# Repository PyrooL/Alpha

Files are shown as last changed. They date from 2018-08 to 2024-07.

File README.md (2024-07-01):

# Alpha 

A 28-key semi-ortholinear mechanical keyboard designed by PyroL.

example

###### Photo by /u/Polyzhu.

## History

[First ever post](https://www.reddit.com/r/MechanicalKeyboards/comments/7nz4ge/ic_i_was_challenged_to_reduce_the_gherkin_and/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)

[PCB protos arrive](https://www.reddit.com/r/MechanicalKeyboards/comments/887hxn/its_so_cute_c/?ref=share&ref_source=link)

[GB opens](https://www.reddit.com/r/MechanicalKeyboards/comments/8djw3d/gb_alpha_28key_keyboard/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)

# Build instructions

## Parts

- [ ] 1x Alpha PCB
- [ ] 28x 1N4148 or equivalent diodes
- [ ] 1x Pro Micro (**NOTE:** USB-C ports are experiencing some clearance issues since it's taller than Micro-B)
- [ ] 1x Case or plate set
- [ ] 5x 10mm M3 standoffs
- [ ] 10x 5mm M3 screws
- [ ] 28x MX, Alps, or Kailh Choc style switches of your choice
- [ ] 1x Micro USB cable

## Tools

- [ ] Soldering station
- [ ] Wire cutter
- [ ] Screwdriver

## Before you start

Orient the PCB correctly before you start the build: the blockers on the side closer to you, and the Pro Micro holes on the left. You should be able to read the "Too. Many. Keys." slogan on the side facing up.

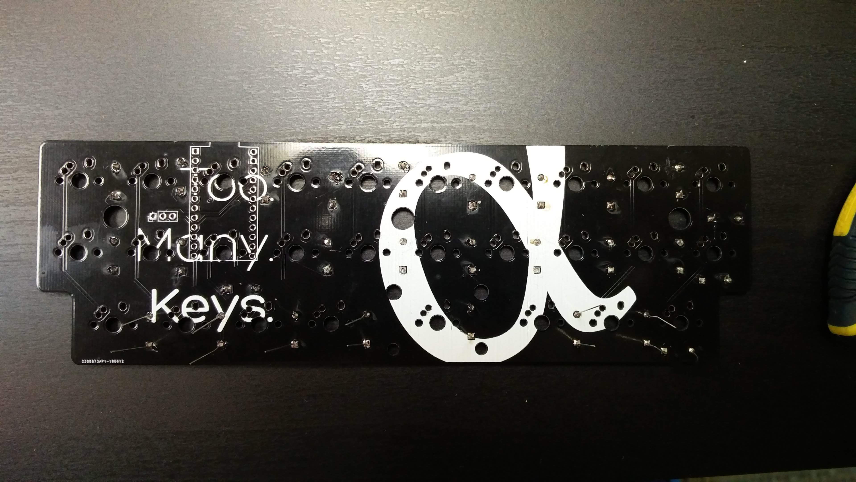
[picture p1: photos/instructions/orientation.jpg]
orientation
 

(OPTIONAL): Install a 2u stabilizer.

## Step 1: Diodes

Install and solder the diodes on the bottom of the PCB, with the black line facing the square pad. Cut the excess leads. 

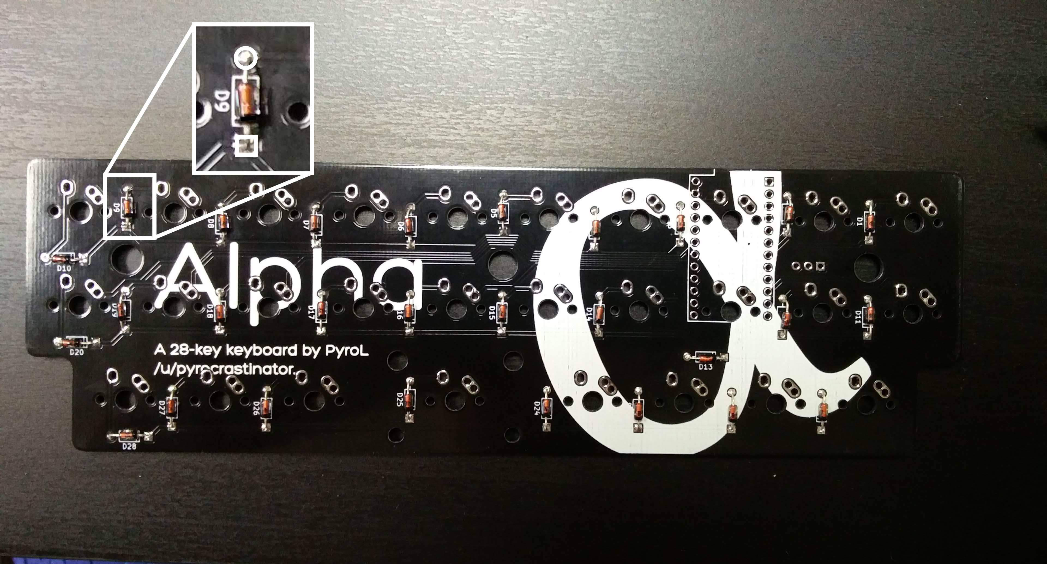
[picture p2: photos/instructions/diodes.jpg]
diodes


## Step 2: Pro Micro
Insert the short side of the Pro Micro standoffs into the bottom of the PCB, and solder them in from the top.

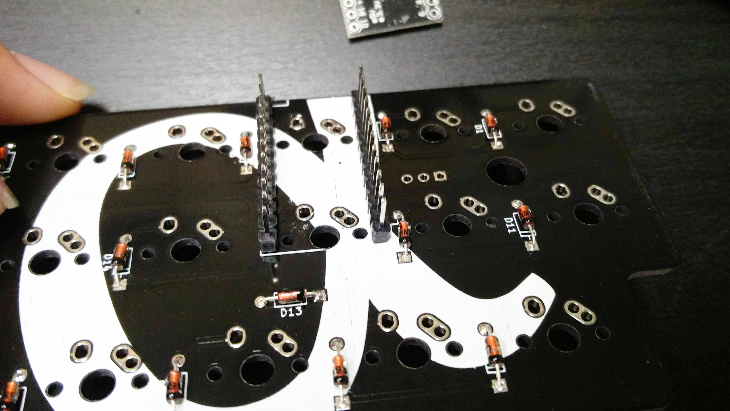
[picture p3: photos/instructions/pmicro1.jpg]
pmicro standoff bottom


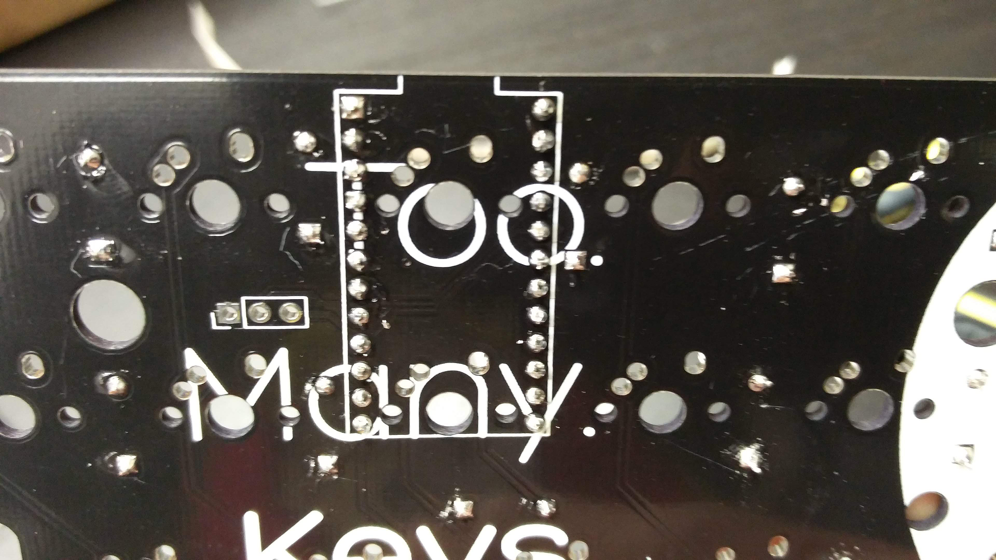
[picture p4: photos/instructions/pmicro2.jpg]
pmicro standoff soldered


Mount the two switches that will sit in between the Pro Micro standoffs in the plate and solder them into the PCB at that location. Clip the extruding switch pins after soldering to ensure the Pro Micro will sit flat. 

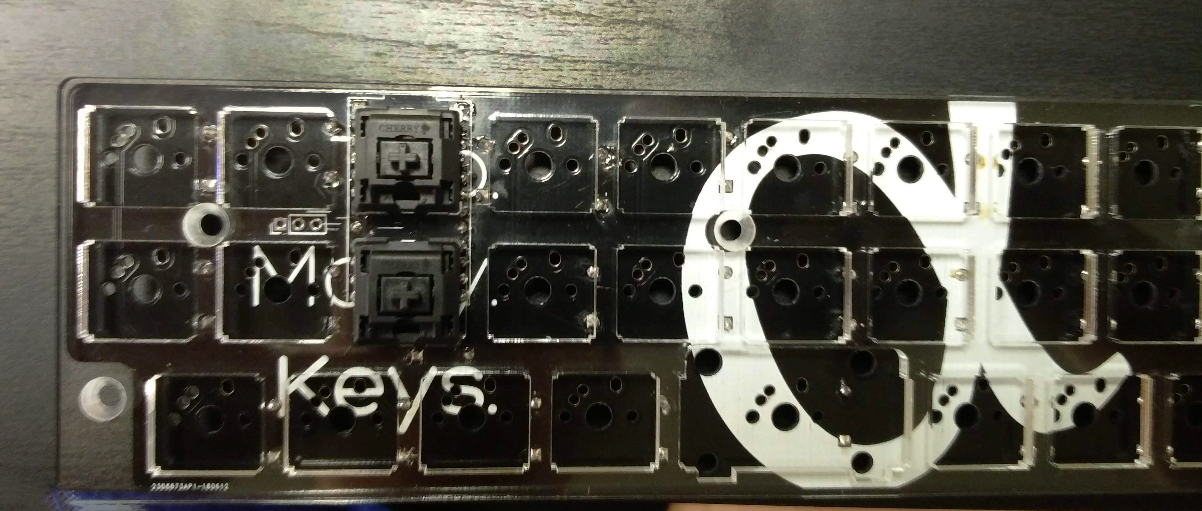
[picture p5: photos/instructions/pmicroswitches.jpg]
pmicro switches


Mount the Pro Micro on the bottom of the PCB, smooth side facing you. Solder.

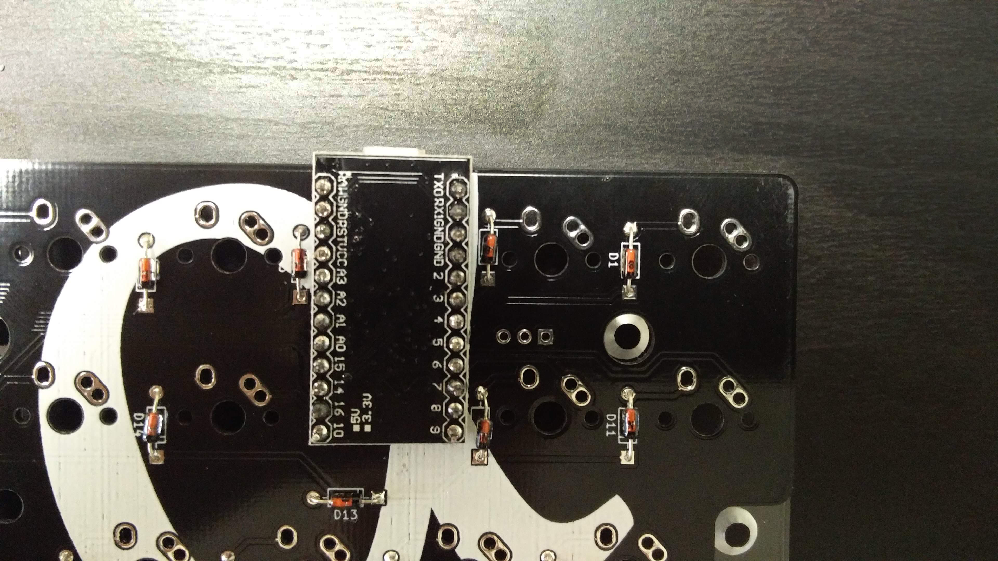
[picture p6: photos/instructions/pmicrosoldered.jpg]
pmicro


[bakingpy has an awesome guide](https://imgur.com/a/M9r3EW9) for an even lower-profile Pro Micro mounting solution that works with Alpha!

**Very important:** after soldering, (regardless of if you mounted normally or bakingpy-style,) use a wire cutter to clip as much of the protruding standoff as possible. With 10mm standoffs this is a snug fit, and it is impossible with the standoffs at full length. Reflow your solder if it climbed up the wire.

## Step 3: Switches

Mount the switches in the plate, and solder them all in. Careful for bent pins!

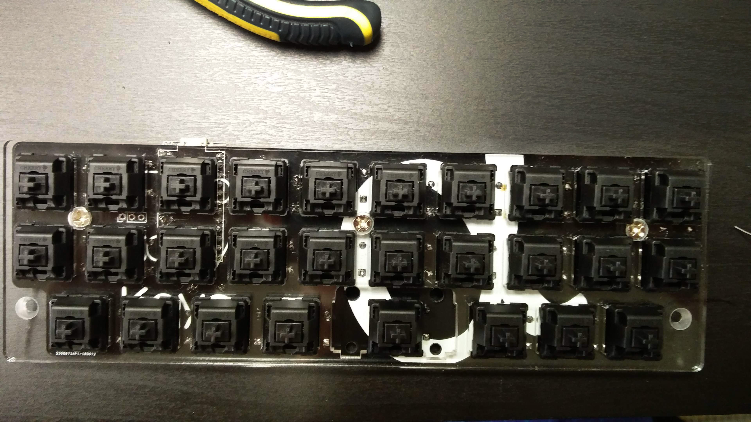
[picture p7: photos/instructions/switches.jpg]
switches


## Step 4 (OPTIONAL): LED strip

Remove the 3M adhesive strip on the back of your LED strip and place it on the bottom of the PCB. Cut 3 wires of similar length, preferably of different colors. Connect VCC, GND, and Data pins on the strip to their respective pins on the PCB.

v1.1 and onwards has pins labeled and in the same order as they come on the strip!

[**If you are using a v1.0 PCB (one that does not have RGB pins or version number labeled) see here for wiring guide**](photos/instructions/rgb.jpg)

## Step 5: Case and firmware

Assemble the case: for each hole, pass a screw through the top plate, screw in a standoff to finger tightness, then screw in through the bottom plate. Once all screws and standoffs are installed, use a screwdriver to tighten as needed (but not too tight, as acrylic can be brittle!). Flash using QMK (use my firmware, or kbfirmware.com), and enjoy!

Flash steps:

- Download [QMK Toolbox](https://github.com/qmk/qmk_toolbox)
- Ensure that you have an appropriate firmware file.
  - For Vial, you can download one off of [keyboard.gay](https://keyboard.gay)
- Open QMK Toolbox. Plug your PCB in, and press the SKQG reset button (or short the appropriate headers). You should see the device connect for ~10 seconds, then disconnect.
- Within QMK Toolbox, choose your appropriate firmware file, then check the "Auto-Flash" button.
- Reset your board again. The firmware should be automatically flashed onto the board.

Don't forget to send me a pic of your build at @PyroL#7672 on Discord or /u/pyrocrastinator! I'd love to see what you guys do with these! 

# Changelog
* v1.1 3/2/19

Added SKQG reset button pads (no need to manually short reset!) and fixed RGB pin order to match common SK6812/WS2812 pinout, and added silkscreen labels to RGB pins.

* v1.2 4/27/19

Diodes now are combo through-hole and SMD compatible! Breakout pins for artisan column ("tmo28") added on both sides. Routing cleaned up etc. 

* v2.0 7/21/19

Choc footprints added! Also support for first version of "TMO28", an artisan column that's still being worked on. 

* v2.1 9/1/19

Fixed disconnected D4, see [here](https://www.instagram.com/p/B15MHgMnYID/?igshid=1266ym89zlw4w) or contact me for fix if you are affected. Only affects v2.0.

* v2.2 7/24/20

Removed TMO28 breakout pins for cleaner look. Version with breakouts still available in `breakoutholes` branch.

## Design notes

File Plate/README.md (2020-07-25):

# Instructions

SVG and Illustrator file for top and bottom plate. If importing into a CAD program, convert it to DXF first or verify the dimensions are correct when you import it. 

Countersinking mounting holes may be done manually with a drill press.

3mm acrylic needs a cutout for stab wire.

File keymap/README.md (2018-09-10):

# A guide to the keymap

In this document I will go through the basic functionality of the Alpha's default keymap. Several functions are kept consistent throughout all the layers. 

 - last key on the 2nd row toggles the next layer. This is not a hold function, just one tap switches.

 - The key to the left of the spacebar returns to the home layer.

The default keymap is somewhat organized by function:

 - Home layer: All letters, spacebar is shift on hold.

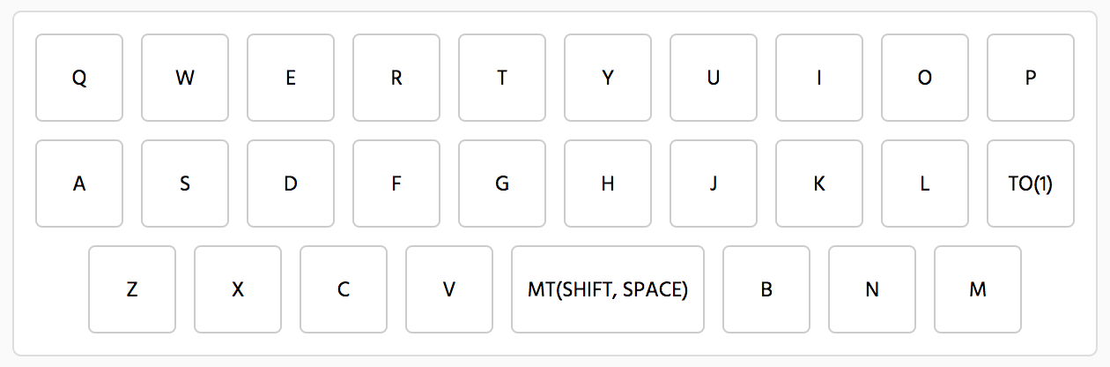
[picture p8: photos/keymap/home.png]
home layer
 

 - Mod layer 1: numbers on top row, vim keys, essential punctuation, and essential mods (Ctrl, OS, Alt, Backspace, Tab, Esc). Enter is on spacebar tap, but shift works the same way. 
 
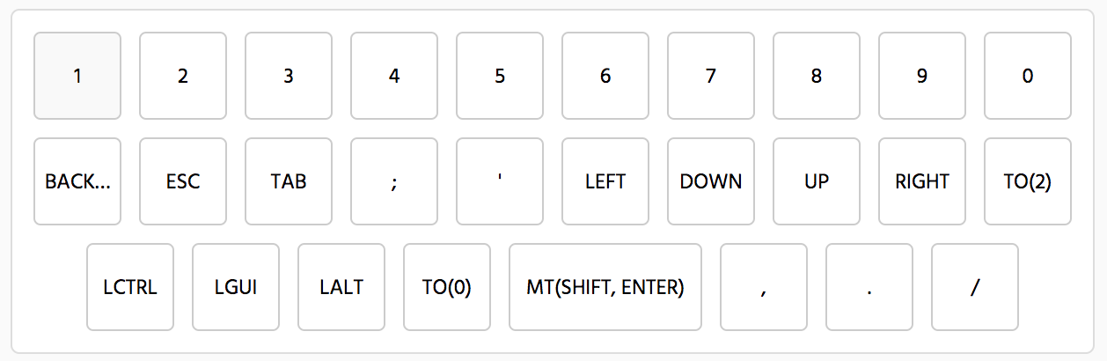
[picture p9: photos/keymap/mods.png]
mods
 

 - Mod layer 2: function keys, RGB control, basic media controls, and math. 
 
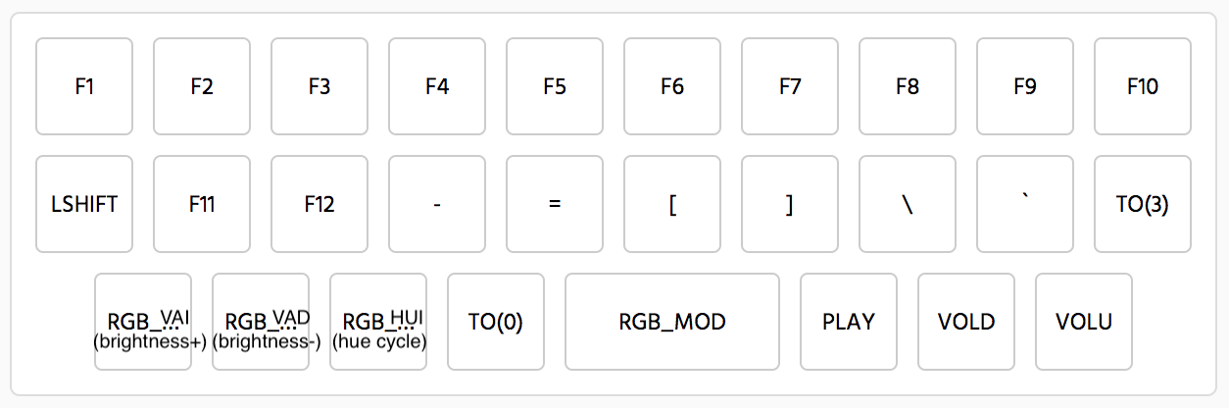
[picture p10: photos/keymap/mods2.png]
mods 2


The final layer has a soft reset button on Q, and spacebar is macro with a special little message from me :)

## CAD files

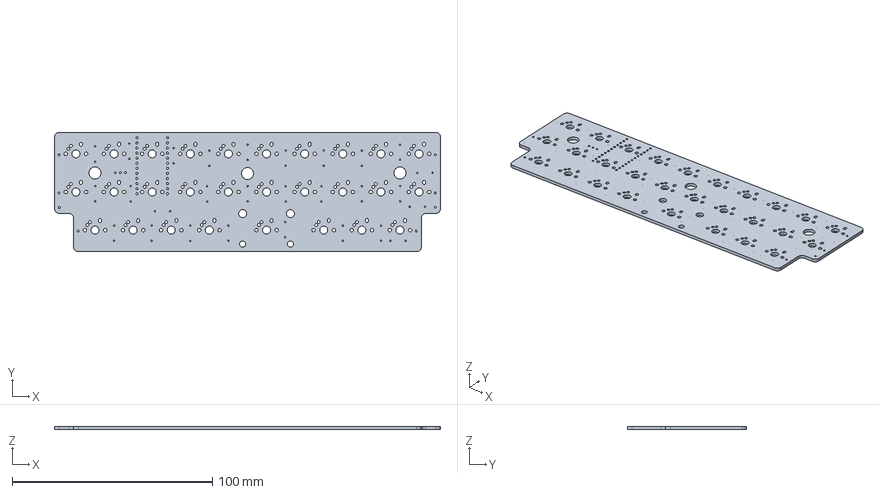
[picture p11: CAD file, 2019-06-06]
PCB_kicad/alpha_pro_micro.step
192.9 x 59.5 x 1.60 mm

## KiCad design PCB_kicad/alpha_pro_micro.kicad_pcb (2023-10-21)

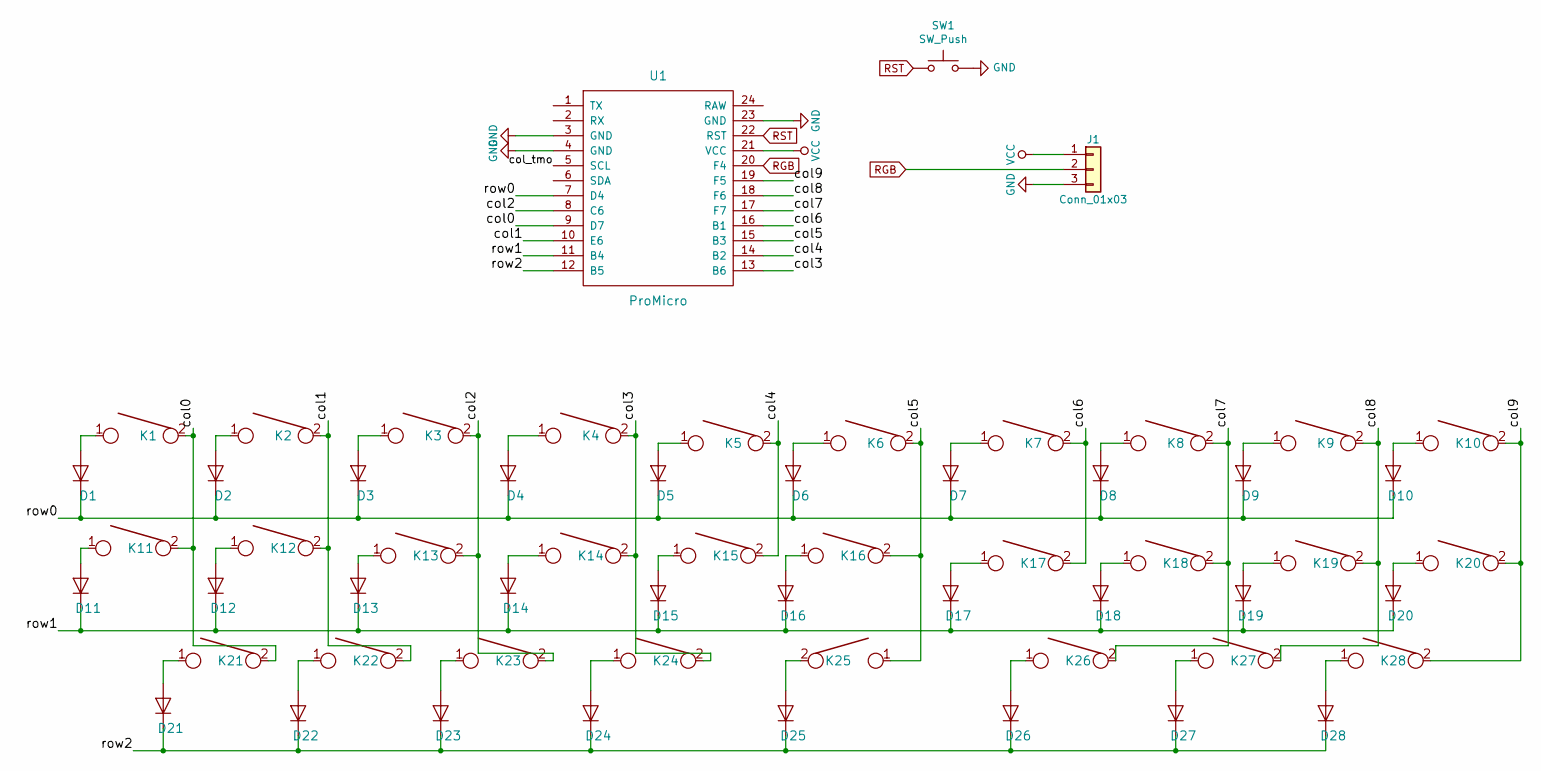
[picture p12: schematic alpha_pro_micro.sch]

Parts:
D1, D2, D3, D4, D5, D6, D7, D8, D9, D10, D11, D12, D13, D14, D15, D16, D17, D18, D19, D20, D21, D22, D23, D24, D25, D26, D27, D28: D; ComboDiode
J1: Conn_01x03; Pin_Header_Straight_1x03_Pitch2.54mm
K1, K2, K3, K4, K5, K6, K7, K8, K9, K10, K11, K12, K13, K14, K15, K16, K17, K18, K19, K20, K21, K22, K23, K24, K26, K27, K28: KEYSW; MX-Alps-Choc-1U-NoLED
K25: KEYSW; MX-Alps-Choc-2U-StabFlip
SW1: SW_Push; SKQG-1155865
U1: ProMicro

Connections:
/col0: K1.2, K11.2, K21.2, U1.9 (D7)
/col1: K2.2, K12.2, K22.2, U1.10 (E6)
/col2: K3.2, K13.2, K23.2, U1.8 (C6)
/col3: K4.2, K14.2, K24.2, U1.13 (B6)
/col4: K5.2, K15.2, U1.14 (B2)
/col5: K6.2, K16.2, K25.1, U1.15 (B3)
/col6: K7.2, K17.2, U1.16 (B1)
/col7: K8.2, K18.2, K26.2, U1.17 (F7)
/col8: K9.2, K19.2, K27.2, U1.18 (F6)
/col9: K10.2, K20.2, K28.2, U1.19 (F5)
/col_tmo: U1.5 (SCL)
/row0: D1.1 (K), D2.1 (K), D3.1 (K), D4.1 (K), D5.1 (K), D6.1 (K), D7.1 (K), D8.1 (K), D9.1 (K), D10.1 (K), U1.7 (D4)
/row1: D11.1 (K), D12.1 (K), D13.1 (K), D14.1 (K), D15.1 (K), D16.1 (K), D17.1 (K), D18.1 (K), D19.1 (K), D20.1 (K), U1.11 (B4)
/row2: D21.1 (K), D22.1 (K), D23.1 (K), D24.1 (K), D25.1 (K), D26.1 (K), D27.1 (K), D28.1 (K), U1.12 (B5)
GND: J1.3, SW1.2, U1.3 (GND), U1.4 (GND), U1.23 (GND)
unnamed: D1.2 (A), K1.1
unnamed: D2.2 (A), K2.1
unnamed: D3.2 (A), K3.1
unnamed: D4.2 (A), K4.1
unnamed: D5.2 (A), K5.1
unnamed: D6.2 (A), K6.1
unnamed: D7.2 (A), K7.1
unnamed: D8.2 (A), K8.1
unnamed: D9.2 (A), K9.1
unnamed: D10.2 (A), K10.1
unnamed: D11.2 (A), K11.1
unnamed: D12.2 (A), K12.1
unnamed: D13.2 (A), K13.1
unnamed: D14.2 (A), K14.1
unnamed: D15.2 (A), K15.1
unnamed: D16.2 (A), K16.1
unnamed: D17.2 (A), K17.1
unnamed: D18.2 (A), K18.1
unnamed: D19.2 (A), K19.1
unnamed: D20.2 (A), K20.1
unnamed: D21.2 (A), K21.1
unnamed: D22.2 (A), K22.1
unnamed: D23.2 (A), K23.1
unnamed: D24.2 (A), K24.1
unnamed: D25.2 (A), K25.2
unnamed: D26.2 (A), K26.1
unnamed: D27.2 (A), K27.1
unnamed: D28.2 (A), K28.1
RGB: J1.2, U1.20 (F4)
RST: SW1.1, U1.22 (RST)
VCC: J1.1, U1.21 (VCC)

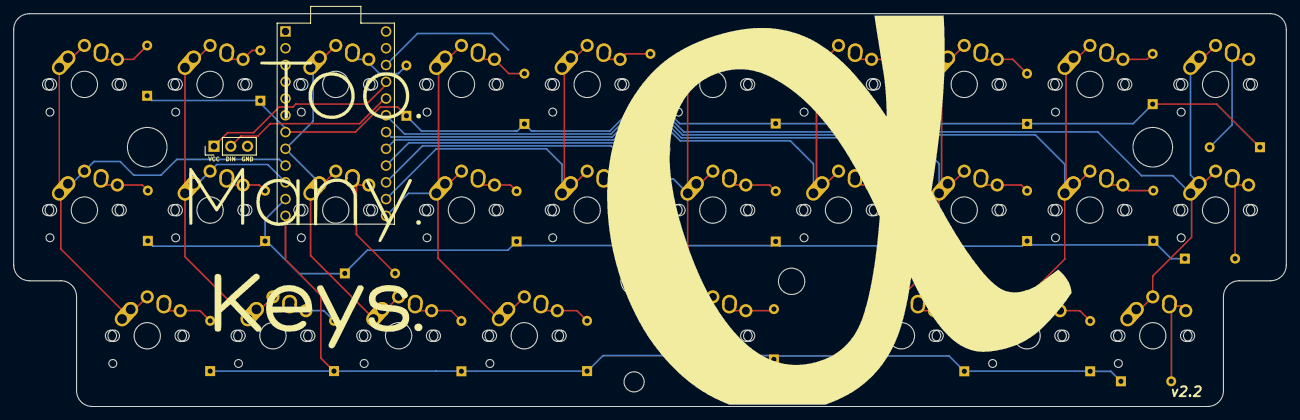
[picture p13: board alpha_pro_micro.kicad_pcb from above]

Board: 2 copper layers, 192.9 x 59.5 mm, 60 parts (1 on the bottom side), 45 nets.

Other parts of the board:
HC1: MountingHole_6mm

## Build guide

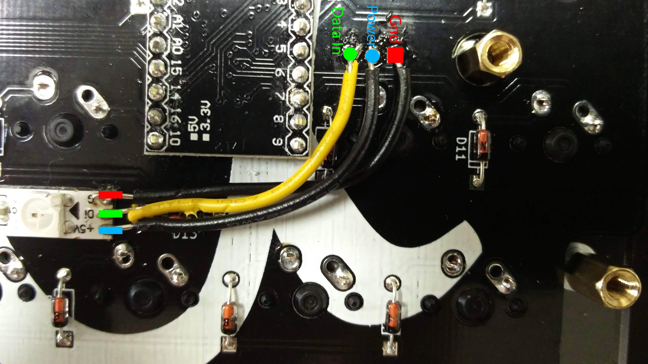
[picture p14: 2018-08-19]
photos/instructions/rgb.jpg

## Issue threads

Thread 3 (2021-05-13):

plate size

IsmaelAlvarez, 2021-05-13:
hi, can we get a small diagram showing the length and width for the plates, for confirmation before cutting.

thanks

PyrooL, 2021-05-17:
The file should be 194 x 122mm. Each plate is 194 x 60.65mm. An easy way to check scaling is if keys are spaced 19.05mm apart.

IsmaelAlvarez, 2021-05-18:
thanks so much

Closed 2021-09-15.

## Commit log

2018-04-12 Add files via upload
    Designs for top and bottom plate.
2018-08-19 added gerbers \o/
2018-09-05 plate readme
2018-09-06 bakingpy pro micro mount
2019-03-03 Alpha v1.1 + design files
    [alpha_pro_micro-2019-02-28-20-26-58.sch, alpha_pro_micro.kicad_pcb, alpha_pro_micro.sch]
2019-03-28 44 years ago we put a man on the moon, yet we still can’t vertically centre things in CSS.
2019-04-27 PCB v1.2!
    [alpha_pro_micro-2019-02-28-20-26-58.sch, alpha_pro_micro.kicad_pcb, alpha_pro_micro.sch]
2019-04-27 v1.2 README + Gerbers
2019-06-06 gerber update
    [alpha_pro_micro-B_Cu.gbl, alpha_pro_micro-B_Mask.gbs, alpha_pro_micro-B_SilkS.gbo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]
2019-07-21 Alpha v2.0 released!
    [alpha_pro_micro.kicad_pcb, alpha_pro_micro.sch]
2019-07-29 updated gerbers
    [alpha_pro_micro-B_Cu.gbl, alpha_pro_micro-B_Mask.gbs, alpha_pro_micro-B_SilkS.gbo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]
2019-09-02 v2.1 released: fixed disconnected D4
    [alpha_pro_micro-B_Cu.gbl, alpha_pro_micro-B_Mask.gbs, alpha_pro_micro-B_SilkS.gbo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]
2020-03-28 removed tmo28 breakouts
    [alpha_pro_micro.kicad_pcb, alpha_pro_micro.sch]
2020-05-04 Clarified plate readme
2022-08-26 compiled v2.2 gerbers
    [alpha_pro_micro-B_Cu.gbl, alpha_pro_micro-B_Mask.gbs, alpha_pro_micro-B_SilkS.gbo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]
2023-10-21 V2.2 gerbers, forgot to push ages ago hehe
    [alpha_pro_micro-B_Cu.gbl, alpha_pro_micro-B_Mask.gbs, alpha_pro_micro-B_SilkS.gbo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]
